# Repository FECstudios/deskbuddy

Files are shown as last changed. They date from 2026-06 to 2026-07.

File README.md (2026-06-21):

# DESK-BUDDY

A desk tool to control audio settings and access some cool macros easily!

We built this device because checking your media controls while you are working on something or while gaming is anoying. It's a compact, 3D-printed desktop companion featuring a 1.8" LCD screen, a rotary encoder, and two touch sensors. 

Instead of cluttering your computer screen, this device mirrors your actions instantly. Rotate the encoder to set the  volume or mute sounds, 

## Gallery
<p align="center">
  
</p>
<p align="center">
circuit_image (1)
</p>
<p align="center"><b>Perf board placement:</b></p>

<p align="center">
  
</p>

<p align="center">
  
</p>

<p align="center">
  
</p>

## What does it do
* **Rotate the encoder** -> Adjust system volume. The 1.8" LCD instantly shows a visual volume slider updating in real-time.
* **Click the encoder** -> Mute audio. The screen status switches to a muted speaker graphic.
* **Touch Sensor 1 (Macro)** -> Triggers a custom PC macro (such as a screenshot or opening youtube) with a visual confirmation popup on the LCD.
* **Touch Sensor 2 (Microphone)** -> Hardware mute toggle for your mic. The screen instantly displays a crossed-out microphone icon so you always know your exact status.

## Hardware
| Component | What it's for |
| :--- | :--- |
| **ESP32 Dev Board (38-pin)** | The microcontroller. Handles inputs, updates the screen state, and talks to the PC. |
| **1.8" ST7735 LCD Screen** | UI Display. Shows active status icons (mic status, volume bar, mute states). |
| **Rotary Encoder (KY-040)** | Digital volume knob + push button for master mute. |
| **TTP223 Touch Sensors (x2)** | Capacitive touch buttons for microphone mute and custom macro shortcuts. |
| **3D-Printed PLA Case** | Custom designed enclosure to fit perfectly into a desktop setup. |

## How it works
The ESP32 connects to your PC via USB and communicates with a lightweight companion script running on your computer to stay perfectly in sync.

1. **Input & Feedback:** When you interact with the hardware (rotating the knob or tapping a touch sensor), the ESP32 sends the command to the PC and instantly updates its own screen to reflect that action.
2. **Status Mirroring:** If you mute your microphone via the touch sensor, the PC script confirms the action, and the 1.8" LCD switches the UI to show a clear crossed-out microphone indicator. No more guessing if you are muted during Discord calls or online sessions.
3. **UI Rendering:** The screen acts as a dedicated hardware dashboard, drawing clean icons and progress bars based on the current state of your system audio and inputs.

## Building
1. **Printing**: Print the top.stl part with 0.20 layer height and add a pause on layer 14, then when the print pauses add your touch sensors with wires and pins removed and continue printing untill part is finished.
Then you can print rest of the parts (knob and bottom) normally with layer height of your choice
2. **Soldering**: Solder all of the components according to the schematics given above in *Gallery* and make sure to not burn the plastic while soldering the touch sensors. Solder the esp32 on the bottom of the perf board and solder the TFT screen on top of the esp32 as shown in the pictures above
3. **Assembly**: Slide in the perf board to the bottom part make sure the esp32 and the type c port hole allign and then slide in the rotary encoder on the left side of the bottom part. After all of the components are added simply click in the top and bottom parts together.

*The model was made with 0.4 tolerances in mind*

## Setup

### Prerequisites
* Arduino IDE 
* ESP32 Board Package (configured for 38-pin ESP32 Dev Module)
* Python 3.x (for the PC side volume/mic control script)
* Libraries: `Adafruit_GFX`, `Adafruit_ST7735`, `SPI`, `FreeSansBold18pt7b`, `FreeSans9pt7b` 

1. Upload `codes/deskbuddy.ino` to your ESP32 using the Arduino IDE (use a USB cable that supports data transfer).
2. Verify that all hardware components are working correctly.
3. Download `codes/sender.py` and install the required dependencies:

```bash
python -m pip install pyserial pycaw comtypes
```

4. Run:

```bash
python sender.py
```

Wait for the ESP32 to be detected, and you're ready to go.

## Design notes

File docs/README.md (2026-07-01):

# DESK-BUDDY

A desk tool to control audio settings and access some cool macros easily!

We built this device because checking your media controls while you are working on something or while gaming is anoying. It's a compact, 3D-printed desktop companion featuring a 1.8" LCD screen, a rotary encoder, and two touch sensors. 

Instead of cluttering your computer screen, this device mirrors your actions instantly. Rotate the encoder to set the  volume or mute sounds, 

## Project Overview

<p align="center">
  
</p>

## Gallery

### Finished Device

<p align="center">
  
</p>

### Internal Assembly

<p align="center">
  
  
</p>

<p align="center">
  
</p>

### Wiring Diagram

<p align="center">
  
</p>
<p align="center">
  
  (It is not the best or might have some errors on the kicad version im beginner on kicad)
</p>

<p align="center"><i>Complete wiring schematic.</i></p>

## What does it do
* **Rotate the encoder** -> Adjust system volume. The 1.8" LCD instantly shows a visual volume slider updating in real-time.
* **Click the encoder** -> Mute audio. The screen status switches to a muted speaker graphic.
* **Touch Sensor 1 (Macro)** -> Triggers a custom PC macro (such as a screenshot or opening youtube) with a visual confirmation popup on the LCD.
* **Touch Sensor 2 (Microphone)** -> Hardware mute toggle for your mic. The screen instantly displays a crossed-out microphone icon so you always know your exact status.

## Hardware
| Component | What it's for |
| :--- | :--- |
| **ESP32 Dev Board (38-pin)** | The microcontroller. Handles inputs, updates the screen state, and talks to the PC. |
| **1.8" ST7735 LCD Screen** | UI Display. Shows active status icons (mic status, volume bar, mute states). |
| **Rotary Encoder (KY-040)** | Digital volume knob + push button for master mute. |
| **TTP223 Touch Sensors (x2)** | Capacitive touch buttons for microphone mute and custom macro shortcuts. |
| **3D-Printed PLA Case** | Custom designed enclosure to fit perfectly into a desktop setup. |

## Bill of Materials (BoM)

| Part | Qty | Approx. Cost (TL) | Purchase Link |
|---|----:|---:|---|
| ESP-WROOM-32D Development Board (38-pin, USB-C) | 1 | 386.40 | https://www.robo90.com/esp-wroom-32-wifi-ve-bluetooth-gelistirme-karti-38-pin-esp32 |
| 1.8" 128×160 TFT LCD (ST7735) | 1 | 488.11 | https://www.robotistan.com/18-inc-lcd-display-module |
| KY-040 Rotary Encoder Module | 1 | 39.91 | https://www.komponentci.net/ky-040-rotary-encoder-modulu-pmu4057 |
| TTP223B Touch Sensor | 2 | 33.12 | https://www.robo90.com/tpp223b-dokunmatik-touch-sensor-modulu |
| **Total Estimated Cost** | | **₺947.54** | |

> Prices are approximate and may change over time.

## How it works
The ESP32 connects to your PC via USB and communicates with a lightweight companion script running on your computer to stay perfectly in sync.

1. **Input & Feedback:** When you interact with the hardware (rotating the knob or tapping a touch sensor), the ESP32 sends the command to the PC and instantly updates its own screen to reflect that action.
2. **Status Mirroring:** If you mute your microphone via the touch sensor, the PC script confirms the action, and the 1.8" LCD switches the UI to show a clear crossed-out microphone indicator. No more guessing if you are muted during Discord calls or online sessions.
3. **UI Rendering:** The screen acts as a dedicated hardware dashboard, drawing clean icons and progress bars based on the current state of your system audio and inputs.

## Steps to Reproduce
1. **Printing**: Print the top.stl part with 0.20 layer height and add a pause on layer 14, then when the print pauses add your touch sensors with wires and pins removed and continue printing untill part is finished.
Then you can print rest of the parts (knob and bottom) normally with layer height of your choice
2. **Soldering**: Solder all of the components according to the schematics given above in *Gallery* and make sure to not burn the plastic while soldering the touch sensors. Solder the esp32 on the bottom of the perf board and solder the TFT screen on top of the esp32 as shown in the pictures above
3. **Assembly**: Slide in the perf board to the bottom part make sure the esp32 and the type c port hole allign and then slide in the rotary encoder on the left side of the bottom part. After all of the components are added simply click in the top and bottom parts together.

The model was made with 0.4 tolerances in mind

## Setup

### Prerequisites
* Arduino IDE 
* ESP32 Board Package (configured for 38-pin ESP32 Dev Module)
* Python 3.x (for the PC side volume/mic control script)
* Libraries: `Adafruit_GFX`, `Adafruit_ST7735`, `SPI`, `FreeSansBold18pt7b`, `FreeSans9pt7b` 

1. Upload `codes/deskbuddy.ino` to your ESP32 using the Arduino IDE (use a USB cable that supports data transfer).
2. Verify that all hardware components are working correctly.
3. Download `codes/sender.py` and install the required dependencies:

```bash
python -m pip install pyserial pycaw comtypes
```

4. Run:

```bash
python sender.py
```

Wait for the ESP32 to be detected, and you're ready to go.

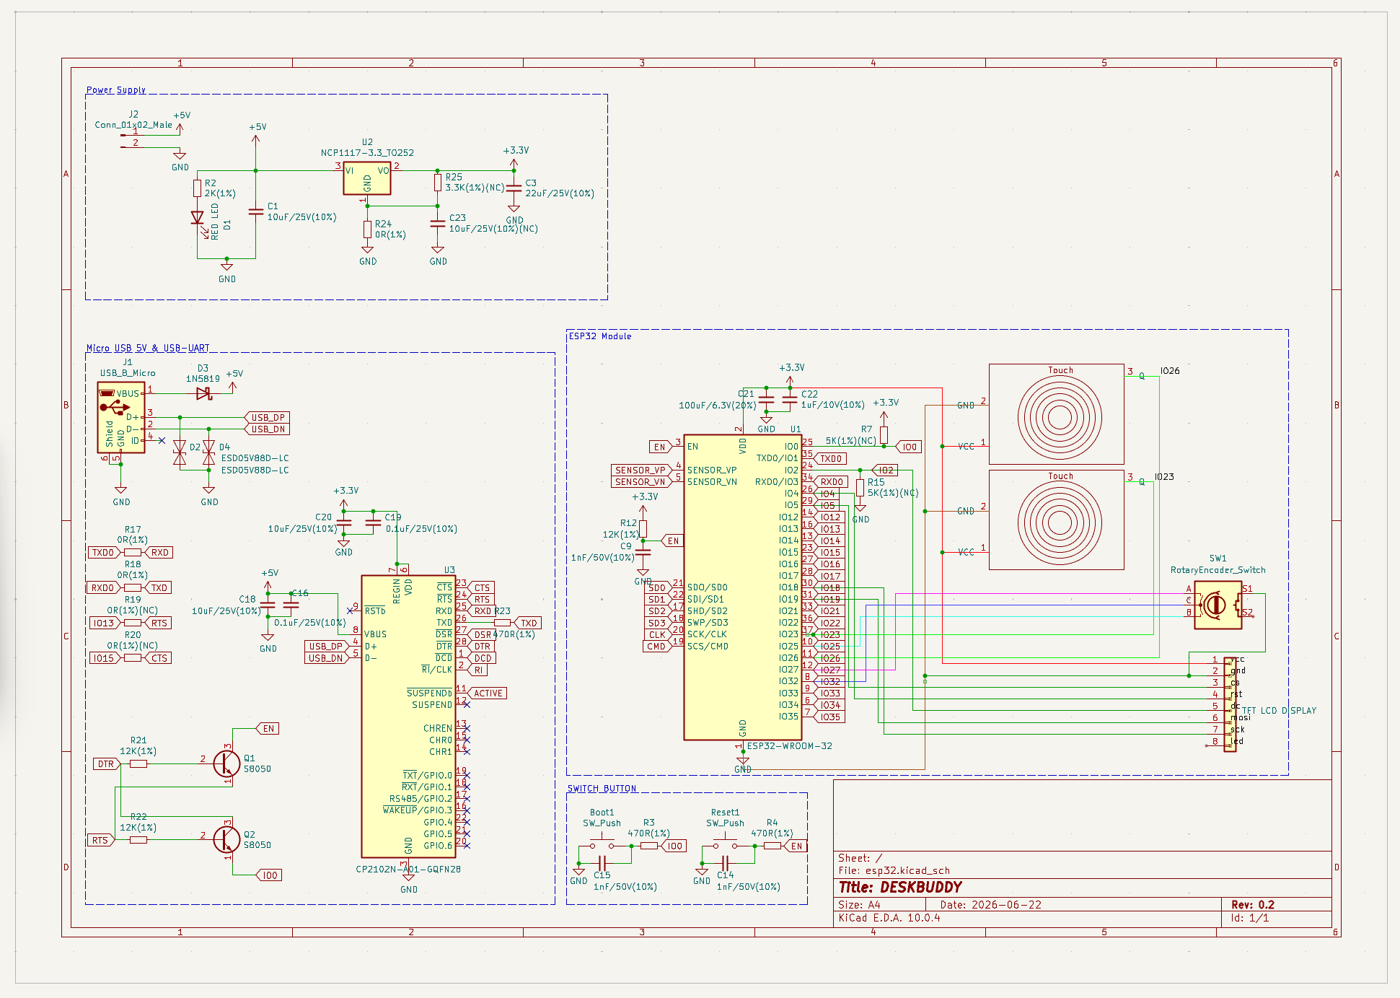
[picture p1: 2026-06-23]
schematics/image.png

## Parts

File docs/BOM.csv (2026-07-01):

Part Name | Quantity | Price | Link
Touch Sensor TTP223B | 2 | 16,56TL | https://www.robo90.com/tpp223b-dokunmatik-touch-sensor-modulu
128x160, General 1.8 inch LCD display Module | 1 | 488.11 TL | https://www.robotistan.com/18-inc-lcd-display-module
KY-040 Rotary Encoder Module | 1 | 39,91TL | https://www.komponentci.net/ky-040-rotary-encoder-modulu-pmu4057
Esp-Wroom-32D (type-c) | 1 | 386,40TL | https://www.robo90.com/esp-wroom-32-wifi-ve-bluetooth-gelistirme-karti-38-pin-esp32
Total Price |  | **₺947.54**

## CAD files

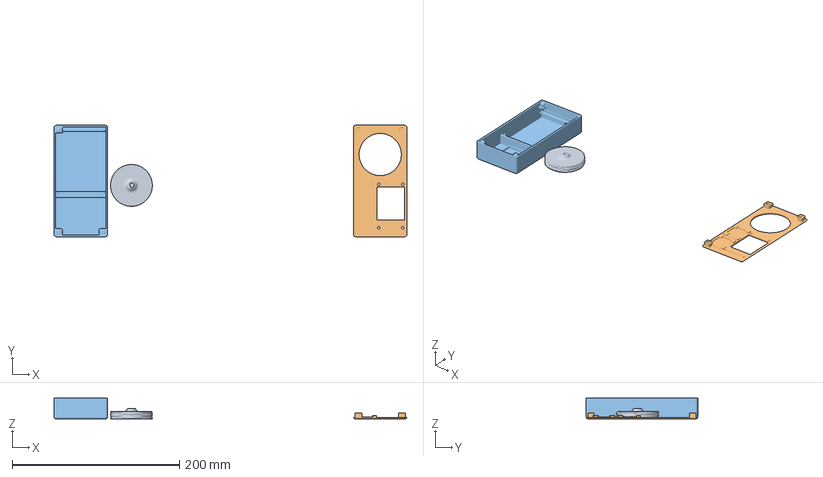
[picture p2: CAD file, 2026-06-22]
3dprint/deskbuddy.3mf
422.0 x 133.3 x 25.0 mm
knob.stl
top.stl
bottom.stl

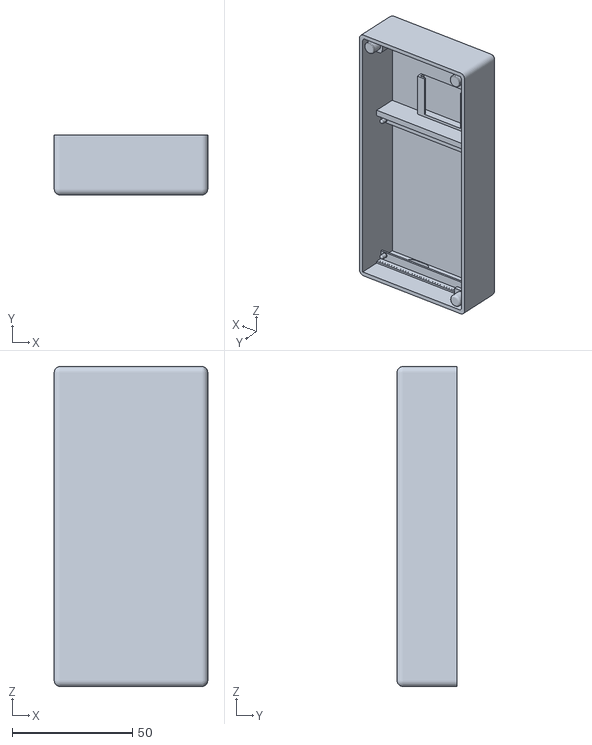
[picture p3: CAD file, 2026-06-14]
3dprint/bottom.stl
64.0 x 25.0 x 133.3

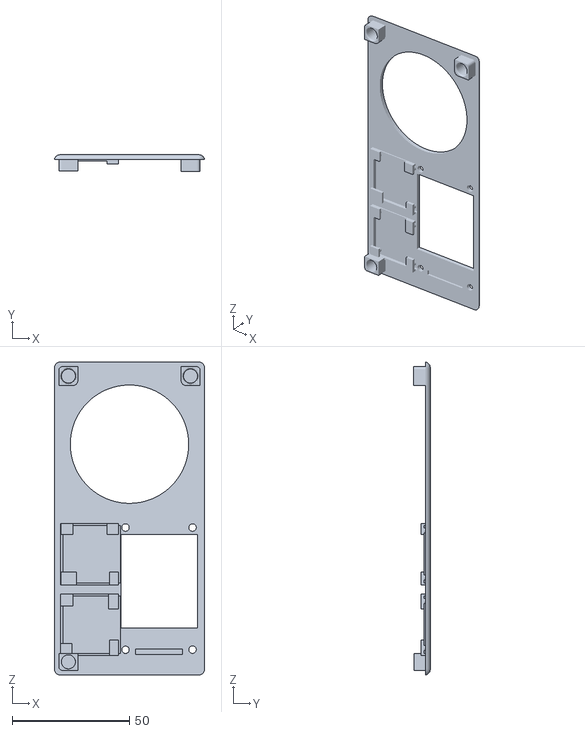
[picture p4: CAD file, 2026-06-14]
3dprint/top.stl
64.0 x 7.10 x 133.3

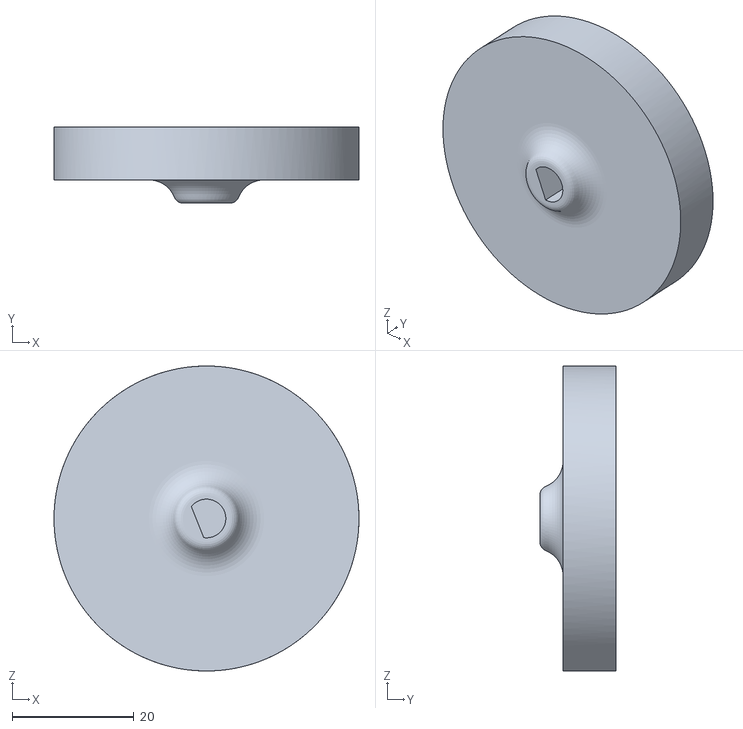
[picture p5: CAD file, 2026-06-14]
3dprint/knob.stl
50.0 x 12.5 x 50.0

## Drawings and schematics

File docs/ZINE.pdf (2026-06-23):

# D E S K B U D D Y

# your favorIte utIlIty tool

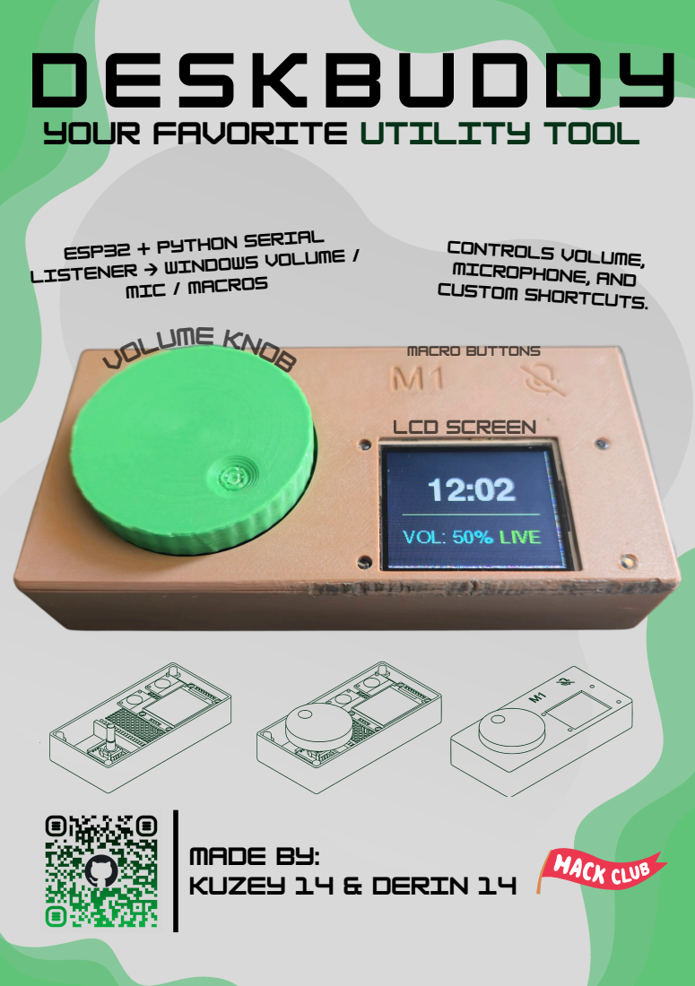
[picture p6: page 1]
Volume Knob; LCD SCreen; MACRO BUTTONS; Made by: Kuzey 14 & DerIn 14; Controls volume, mIcrophone, and custom shortcuts.; ESP32 + Python serIal; mIc / macros

lIstener → WIndows volume /

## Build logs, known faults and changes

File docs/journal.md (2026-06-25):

# DeskBuddy

- Exported at: 2026-06-21T15:25:05Z
- Project ID: 4344
- Entries: 17
- Exported from fallout and recorded via lookout

Message to the Horizons team:

If you could count the hours filmed via lookout it would mean a lot we tried to transfer this project from Fallout to Horizons due to visa reasons (the project has not been submitted to Fallout)

## Entry 1
- ID: 12566
- Author: D_R1N
- Created At: 2026-06-08T18:42:00Z
- 1h 4m tracked

### Content

Today I worked on the Desk Buddy project by learning and using KiCad to create and improve the circuit design. I also designed a poster to showcase the project, focusing on explaining its purpose, functionality, and key features in a clear and visually appealing format.

### Recording Links

- https://lookout.hackclub.com/api/media/732c8ba0-a21a-4e1c-85cd-4a641441a240/video.mp4
  


## Entry 2
- ID: 13017
- Author: 
- Created At: 2026-06-10T15:07:04Z
- 3h 50m tracked

### Content
Today I soldered the ESP and display onto the perfboard, completed the main hardware assembly, and ran a series of tests to make sure everything was working correctly. After fixing a few small issues, the setup was running as expected and ready for the next stage of development.

### Recording Links

- https://lookout.hackclub.com/api/media/19390815-d58f-4c3a-a059-772953b4d734/video.mp4



## Entry 3
- ID: 13019
- Author: craftfec
- Created At: 2026-06-10T15:11:53Z
- 1h 13m tracked

### Content

Today i worked on the knob design more than i should have and printed it but it still doesn't look very well

### Recording Links

- https://lookout.hackclub.com/api/media/c3755179-fb84-44b6-8a31-3a1aa7dcd7ff/video.mp4
  


## Entry 4
- ID: 13289
- Author: craftfec
- Created At: 2026-06-11T19:11:07Z
- 3h 4m tracked

### Content

This was the designing process of the DeskBuddy sadly i uploaded the video a few days after filming so hope you enjoy it 
Also i learned about connecting 3d printed parts while making this design

### Recording Links

- https://lookout.hackclub.com/api/media/a92febf3-f74a-4c93-ac2f-3d8974450e7d/video.mp4

## Entry 5
- ID: 13423
- Author: 
- Created At: 2026-06-12T09:11:34Z
- 3h 17m tracked

### Content

Spent some time working on DeskBuddy today. I soldered the rotary encoder and LCD display onto the perfboard, then wrote and ran test code to make sure everything was working properly. The tests went well and it's exciting to see the project slowly coming together.

### Recording Links

- https://lookout.hackclub.com/api/media/f283b0ac-b732-48af-818a-40508e89c2a5/video.mp4



## Entry 6
- ID: 13424
- Author: 
- Created At: 2026-06-12T09:16:55Z
- 44min tracked

### Content

Continued working on the DeskBuddy electronics today, focusing on soldering and assembly. While I worked on the hardware, my friend spent time refining the design and printing updated parts. Working on different areas simultaneously helped us move the project forward much faster.

### Recording Links

- https://www.youtube.com/watch?v=BgmVbupuWS4
  


## Entry 7
- ID: 13962
- Author: 
- Created At: 2026-06-14T12:47:21Z
- 1h 8m tracked

### Content

Spent some time working on DeskBuddy today. I soldered more of the components and kept building out the electronics. When I needed a break from soldering, I started designing the poster for the project and played around with a few different ideas for the layout.

### Recording Links

- https://lookout.hackclub.com/api/media/d2c67cb4-1a42-4405-bd3e-0cb8356158ea/video.mp4


## Entry 8
- ID: 14080
- Author: craftfec
- Created At: 2026-06-14T19:46:14Z
- 1h 30m tracked

### Content

Today i got most of the files ready for shipping. Created the GitHub repo and filled it with help from Derin, also wrote some test codes i successfully wrote the receiver code which will be a python script run from the pc and uploaded the CAD and 3d print files.

### Recording Links

- https://lookout.hackclub.com/api/media/ca90fd3a-f077-4b0d-8939-126cdd796fb7/video.mp4
  


## Entry 9
- ID: 14316
- Author: 
- Created At: 2026-06-15T20:44:35Z
- 6h 10m tracked

### Content

Today, I worked on my DeskBuddy project. I completed the soldering work, tested the code to ensure everything runs smoothly, and 3D printed its custom case. It was a productive day of combining hardware, software, and design.

### Recording Links

- https://lookout.hackclub.com/api/media/cef48a1d-7b74-49a0-b643-4330191fc3d0/video.mp4



## Entry 10
- ID: 14508
- Author: 
- Created At: 2026-06-16T12:30:20Z
- 1h tracked

### Content

Today, I focused on the DeskBuddy project. I finalized the Bill of Materials (BOM), completed the sensor testing and successfully updated the GitHub README. It was a productive day of documenting the hardware framework and ensuring all system diagnostics run smoothly.

### Recording Links

- https://lookout.hackclub.com/api/media/01b8f960-ebd3-4d82-9f8d-2516ebf4a3a7/video.mp4
- https://lookout.hackclub.com/api/media/e4955757-c1b6-4c76-b939-bbf9b6c7b74f/video.mp4



## Entry 11
- ID: 14593
- Author: 
- Created At: 2026-06-16T18:19:18Z
- 1h tracked

### Content

Today I spent some time improving DeskBuddy. I worked on the codebase, fixing issues and adding new functionality to make everything run more smoothly. I also continued refining the 3D design, making adjustments to improve both the appearance and the overall usability of the device. It's starting to feel much more polished, and I'm excited to keep pushing the project forward

### Recording Links

- https://lookout.hackclub.com/api/media/e6145abb-b70c-4924-bf2d-8ee2b85bff13/video.mp4


## Entry 12
- ID: 14983
- Author: craftfec
- Created At: 2026-06-18T12:40:14Z
- 4h 30m tracked

### Content

Today i worked on deskbuddy writing the python and the esp side code and got it working i then added the images to the zine design

### Recording Links

- https://lookout.hackclub.com/api/media/61a2feca-e964-420d-92f1-f0d4123bb827/video.mp4
- https://lookout.hackclub.com/api/media/8fe47c0b-c181-42f6-a2dc-169a25c2b767/video.mp4



## Entry 13
- ID: 14983
- Author: craftfec
- Created At: 2026-06-21 9:30pm
- Time Tracked: 1:11:46

### Content

Today i tried to transfer the project from fallout to horizons, created both of the projects for me and my teammate and mailed the horizons team about this but still no response...

### Recording Links
- https://lapse.hackclub.com/timelapse/802CU1dYqW50
- https://lapse.hackclub.com/timelapse/G2JajRXwvE7z
- https://lapse.hackclub.com/timelapse/nWsz_2K3OGzF

## Entry 14
- ID: 14983
- Author: craftfec
- Created At: 2026-06-22 9:14pm
- Time Tracked: 2:30:41
  
### Content

Today i started to finalize the shipping process, made schematics on both circitdesigner and kicad, created print profiles for the projects and uploaded them to makerworld https://makerworld.com/tr/models/2961161-deskbuddy-smart-media-controller#profileId-3319336



### Recording Links
- https://lapse.hackclub.com/timelapse/zzBnF3nzvdZW
- https://lapse.hackclub.com/timelapse/s5m_3yv74e1e
- https://lapse.hackclub.com/timelapse/giknjamv4afs
- https://lapse.hackclub.com/timelapse/sHuYStKZbtmM

## Entry 15
- ID: 14983
- Author: 
- Created At: 2026-06-22 9:18pm
- Time Tracked: 58:12
  
### Content

Today i tried to paint the project with some metalic gray colors and now i am waiting for the paint to dry and also i worked on the code but sadly the recordings got lost and also i wrote journals



### Recording Links
- https://lapse.hackclub.com/timelapse/VPNcZLikPkJ_
- https://lapse.hackclub.com/timelapse/D4sbDbbKvaBL

## Entry 16
- ID: 14983
- Author: 
- Created At: 2026-06-25 10:25am
- Time Tracked: 1:46:05
  
### Content

Today i continued by getting the project shipping ready. Journaled for the project, made schematic designs on kicad and worked on the poster 



### Recording Links
- https://lapse.hackclub.com/timelapse/ujkxyN6umV80
- https://lapse.hackclub.com/timelapse/iAX3YhSjHB24
- https://lapse.hackclub.com/timelapse/kg9KbqnS6cpq
- https://lapse.hackclub.com/timelapse/9ATnQ195jXJ8

## Entry 17
- ID: 14983
- Author: D_R1N
- Created At: 2026-06-25 10:45am
- Time Tracked: 37:01
  
### Content

Finally the project and the github page is finished now all we need to do is send to review!



### Recording Links
- https://lapse.hackclub.com/timelapse/_qu0E8XzCpRS

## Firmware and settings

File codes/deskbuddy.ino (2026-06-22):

#include <Adafruit_GFX.h>
#include <Adafruit_ST7735.h>
#include <SPI.h>
#include <Fonts/FreeSansBold18pt7b.h>
#include <Fonts/FreeSans9pt7b.h>

// ─── Screen Pin Definitions ───────────────────────────────────────────────────────
#define TFT_CS     5
#define TFT_DC     2
#define TFT_RST    4
#define TFT_MOSI   19
#define TFT_SCLK   18

const int TOUCH_PIN1 = 26;
const int TOUCH_PIN2 = 23;
const int TOUCH_PIN  = TOUCH_PIN1;
const int CLK_PIN   = 25;
const int DT_PIN    = 32;
const int SW_PIN    = 27;

// ─── Display Setup ─────────────────────────────────────────────────────────
Adafruit_ST7735 tft = Adafruit_ST7735(TFT_CS, TFT_DC, TFT_RST);
GFXcanvas16 canvas(160, 128);

// ─── State Variables ───────────────────────────────────────────────────────
int   volume        = 50;
bool isMicMuted     = false;
bool isIncreasing   = true; 

// Idle & Time System
unsigned long lastActivityTime = 0;
const unsigned long IDLE_TIMEOUT = 10000; 
int hr = 12, mn = 0, sc = 0;              
unsigned long lastClockTick = 0;

// Encoder
volatile int encoderDelta = 0;
int lastClkState;

// Button debounce / double-click
bool          lastButtonState  = HIGH;
unsigned long firstClickTime   = 0;
bool          waitingForDouble = false;
const unsigned long DOUBLE_CLICK_MS = 500;

// Touch
bool lastTouchState  = false;
bool lastTouch2State = false;

// ─── Forward Declarations ──────────────────────────────────────────────────
void drawScreen();
void pushCanvas();
void playM1Animation();
void playMuteAnimation();
void sendVolume();
void sendMicState();
void handleSerialInput();
void IRAM_ATTR encoderISR();

// ─── Drawing ───────────────────────────────────────────────────────────────

void drawScreen() {
  canvas.fillScreen(ST7735_BLACK);

  // 1) IDLE SCREEN
  if (millis() - lastActivityTime > IDLE_TIMEOUT) {
    canvas.setFont(&FreeSansBold18pt7b);
    canvas.setTextColor(ST7735_WHITE);
    
    char timeStr[9];
    snprintf(timeStr, sizeof(timeStr), "%02d:%02d", hr, mn);
    
    int16_t x1, y1;
    uint16_t tw, th;
    canvas.getTextBounds(timeStr, 0, 0, &x1, &y1, &tw, &th);
    canvas.setCursor((160 - tw) / 2, 58);
    canvas.print(timeStr);
    
    canvas.drawFastHLine(15, 74, 130, 0x4444);
    
    canvas.setFont(&FreeSans9pt7b);
    
    char volStr[12];
    snprintf(volStr, sizeof(volStr), "VOL: %d%%", volume);
    canvas.setTextColor(ST7735_CYAN);
    canvas.setCursor(15, 104);
    canvas.print(volStr);
    
    if (isMicMuted) {
      canvas.setTextColor(ST7735_RED);
      canvas.setCursor(95, 104);
      canvas.print("MUTED");
    } else {
      canvas.setTextColor(ST7735_GREEN);
      canvas.setCursor(105, 104);
      canvas.print("LIVE");
    }
    return;
  }

  // 2) MIC MUTED SCREEN
  if (isMicMuted) {
    int16_t x1, y1;
    uint16_t tw, th;

    canvas.setFont(&FreeSansBold18pt7b);
    canvas.setTextColor(ST7735_RED);
    canvas.getTextBounds("MIC OFF", 0, 0, &x1, &y1, &tw, &th);
    canvas.setCursor((160 - tw) / 2, 58);
    canvas.print("MIC OFF");

    canvas.setFont(&FreeSans9pt7b);
    canvas.setTextColor(0x7800);
    canvas.getTextBounds("(muted)", 0, 0, &x1, &y1, &tw, &th);
    canvas.setCursor((160 - tw) / 2, 88);
    canvas.print("(muted)");
  }
  // 3) VOLUME CONTROL SCREEN
  else {
    canvas.setFont(&FreeSans9pt7b);
    canvas.setTextColor(isIncreasing ? ST7735_GREEN : ST7735_RED);
    canvas.setCursor(135, 22);
    canvas.print(isIncreasing ? "+" : "-");

    canvas.setFont(&FreeSansBold18pt7b);
    canvas.setTextColor(ST7735_WHITE);

    int16_t  x1, y1;
    uint16_t tw, th;
    char volStr[8];
    snprintf(volStr, sizeof(volStr), "%d", volume);
    canvas.getTextBounds(volStr, 0, 0, &x1, &y1, &tw, &th);

    int numX = (160 - (int)tw - 20) / 2;
    canvas.setCursor(numX, 68);
    canvas.print(volStr);

    canvas.setFont(&FreeSans9pt7b);
    canvas.setTextColor(0xC618);
    canvas.print("%");

    uint16_t barColor = isIncreasing ? ST7735_GREEN : ST7735_RED;
    canvas.drawRoundRect(14, 85, 132, 22, 6, ST7735_WHITE);
    int barW = map(volume, 0, 100, 0, 128);
    if (barW > 0) {
      canvas.fillRoundRect(16, 87, barW, 18, 4, barColor);
    }
  }
}

void pushCanvas() {
  tft.drawRGBBitmap(0, 0, canvas.getBuffer(), 160, 128);
}

void updateDisplay() {
  drawScreen();
  pushCanvas();
}

// ─── M1 Animation ──────────────────────────────────────────────────────────
void playM1Animation() {
  for (int i = 0; i < 3; i++) {
    canvas.fillScreen(ST7735_BLACK);
    pushCanvas();
    delay(25);
  }

  canvas.setFont(&FreeSansBold18pt7b);
  for (int r = 0; r <= 31; r += 3) {
    canvas.fillScreen(ST7735_BLACK);
    canvas.setTextColor(((uint16_t)r) << 11);
    canvas.setCursor(50, 75);
    canvas.print("M1");
    pushCanvas();
    delay(12);
  }

  delay(500);

  for (int r = 31; r >= 0; r -= 3) {
    canvas.fillScreen(ST7735_BLACK);
    canvas.setTextColor(((uint16_t)r) << 11);
    canvas.setCursor(50, 75);
    canvas.print("M1");
    pushCanvas();
    delay(12);
  }

  updateDisplay();
}

void playMuteAnimation() {
  for (int i = 0; i < 3; i++) {
    canvas.fillScreen(ST7735_BLACK);
    pushCanvas();
    delay(25);
  }

  canvas.setFont(&FreeSansBold18pt7b);
  for (int r = 0; r <= 31; r += 3) {
    canvas.fillScreen(ST7735_BLACK);
    canvas.setTextColor(((uint16_t)r) << 11);
    canvas.setCursor(50, 75);
    canvas.print("MUTED");
    pushCanvas();
    delay(12);
  }

  delay(500);

  for (int r = 31; r >= 0; r -= 3) {
    canvas.fillScreen(ST7735_BLACK);
    canvas.setTextColor(((uint16_t)r) << 11);
    canvas.setCursor(50, 75);
    canvas.print("MUTED");
    pushCanvas();
    delay(12);
  }

  updateDisplay();
}

// ─── Serial Communication & Parsing ────────────────────────────────────────
void sendVolume() {
  Serial.print("VOL:");
  Serial.println(volume);
}

void sendMicState() {
  Serial.println(isMicMuted ? "MIC:OFF" : "MIC:ON");
}

void handleSerialInput() {
  while (Serial.available() > 0) {
    String input = Serial.readStringUntil('\n');
    input.trim();
    
    // Expects "TIME:HH:MM:SS"
    if (input.startsWith("TIME:")) {
      int firstColon = input.indexOf(':');
      int secondColon = input.indexOf(':', firstColon + 1);
      int thirdColon = input.indexOf(':', secondColon + 1);
      
      if (firstColon != -1 && secondColon != -1) {
        String hrStr = input.substring(firstColon + 1, secondColon);
        String mnStr = (thirdColon != -1) ? input.substring(secondColon + 1, thirdColon) : input.substring(secondColon + 1);
        String scStr = (thirdColon != -1) ? input.substring(thirdColon + 1) : "0";
        
        hr = hrStr.toInt();
        mn = mnStr.toInt();
        sc = scStr.toInt();
        
        lastClockTick = millis();
        
        if (millis() - lastActivityTime > IDLE_TIMEOUT) {
          updateDisplay();
        }
      }
    }
    else if (input.startsWith("VOL:")) {
      String volStr = input.substring(4);
      int newVolume = volStr.toInt();
      newVolume = constrain(newVolume, 0, 100);
      if (newVolume != volume) {
        volume = newVolume;
        lastActivityTime = millis();
        updateDisplay();
      }
    }
  }
}

// ─── Encoder ISR ───────────────────────────────────────────────────────────
void IRAM_ATTR encoderISR() {
  int clkNow = digitalRead(CLK_PIN);
  if (clkNow != lastClkState && clkNow == LOW) {
    encoderDelta = (digitalRead(DT_PIN) != clkNow) ? 1 : -1;
  }
  lastClkState = clkNow;
}

// ─── Setup ─────────────────────────────────────────────────────────────────
void setup() {
  pinMode(TFT_CS,   OUTPUT);
  pinMode(TFT_DC,   OUTPUT);
  pinMode(TFT_RST,  OUTPUT);
  delay(500);

  Serial.begin(115200);

  pinMode(TOUCH_PIN, INPUT);
  pinMode(TOUCH_PIN2, INPUT);
  pinMode(CLK_PIN,   INPUT_PULLUP);
  pinMode(DT_PIN,    INPUT_PULLUP);
  pinMode(SW_PIN,    INPUT_PULLUP);

  lastClkState = digitalRead(CLK_PIN);
  attachInterrupt(digitalPinToInterrupt(CLK_PIN), encoderISR, CHANGE);

  SPI.begin(TFT_SCLK, -1, TFT_MOSI, TFT_CS);
  tft.initR(INITR_BLACKTAB);
  tft.setRotation(3); 

  canvas.fillScreen(ST7735_BLACK);
  lastActivityTime = millis();
  lastClockTick = millis();
  updateDisplay();

  Serial.println("DeskBuddy ready.");
}

// ─── Loop ──────────────────────────────────────────────────────────────────
void loop() {

  // Update clock in background
  if (millis() - lastClockTick >= 1000) {
    lastClockTick += 1000;
    sc++;
    if (sc >= 60) { sc = 0; mn++; }
    if (mn >= 60) { mn = 0; hr++; }
    if (hr >= 24) { hr = 0; }
    
    if (millis() - lastActivityTime > IDLE_TIMEOUT) {
      updateDisplay();
    }
  }

  handleSerialInput();

  // Handle Encoder
  if (encoderDelta != 0) {
    lastActivityTime = millis();
    int step = 2;

    if (isMicMuted) {
      isMicMuted  = false;
      isIncreasing = true;
      sendMicState();
    } else {
      if (isIncreasing) {
        volume = constrain(volume + (encoderDelta > 0 ? step : -step), 0, 100);
      } else {
        volume = constrain(volume + (encoderDelta > 0 ? -step : step), 0, 100);
      }
      sendVolume();
    }

    encoderDelta = 0;
    updateDisplay();
  }

  // Handle Button
  bool btnNow = digitalRead(SW_PIN);


    // Handle Touch
  bool touch2Now = (digitalRead(TOUCH_PIN2) == HIGH);

  if (touch2Now && !lastTouch2State) {
    lastActivityTime = millis();
    Serial.println("MUTE:RUN");
    isMicMuted = !isMicMuted;
    playMuteAnimation();
    sendMicState();
  }

  lastTouch2State = touch2Now;

  delay(5); 


  if (btnNow == LOW && lastButtonState == HIGH) {
    lastActivityTime = millis();
    unsigned long now = millis();

    volume = 0;
    sendVolume();

    updateDisplay();
  }

  if (waitingForDouble && (millis() - firstClickTime > DOUBLE_CLICK_MS)) {
    isIncreasing    = !isIncreasing;
    waitingForDouble = false;
    updateDisplay();
  }

  lastButtonState = btnNow;

  // Handle Touch
  bool touchNow = (digitalRead(TOUCH_PIN) == HIGH);

  if (touchNow && !lastTouchState) {
    lastActivityTime = millis();
    Serial.println("MACRO:RUN");
    playM1Animation();
  }

  lastTouchState = touchNow;

  delay(5); 
}

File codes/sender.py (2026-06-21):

import sys
import time
import logging
import webbrowser
from ctypes import cast, POINTER


import serial
import serial.tools.list_ports

from comtypes import CLSCTX_ALL, CoInitialize, CoUninitialize
from pycaw.pycaw import AudioUtilities, IAudioEndpointVolume
from pycaw.constants import CLSID_MMDeviceEnumerator
from comtypes.client import CreateObject
from pycaw.pycaw import IMMDeviceEnumerator, EDataFlow, ERole


logging.basicConfig(
    level=logging.INFO,
    format="[%(asctime)s] %(levelname)s  %(message)s",
    datefmt="%H:%M:%S",
)
log = logging.getLogger("DeskBuddy")

BAUD_RATE          = 115200
RECONNECT_DELAY_S  = 3          # seconds between reconnect attempts
READ_TIMEOUT_S     = 1          # serial read timeout
ESP32_USB_IDS      = [          # known ESP32 USB vendor IDs (decimal)
    0x10C4,  # Silicon Labs CP210x
    0x1A86,  # CH340 / CH341
    0x0403,  # FTDI
    0x303A,  # Espressif native USB (ESP32-S3 etc.)
]


# ─── Port Auto-Detection ────────────────────────────────────────────────────

def find_esp32_port() -> str | None:
    """Scan available COM ports and return the first that looks like an ESP32."""
    ports = serial.tools.list_ports.comports()
    for p in ports:
        vid = p.vid  # may be None for ports without USB info
        if vid is not None and vid in ESP32_USB_IDS:
            log.info("Auto-detected ESP32 on %s  (VID=0x%04X, %s)", p.device, vid, p.description)
            return p.device
        # Fallback: description heuristic
        desc = (p.description or "").lower()
        if any(k in desc for k in ("cp210", "ch340", "ch341", "ftdi", "esp", "uart")):
            log.info("Auto-detected likely ESP32 on %s  (%s)", p.device, p.description)
            return p.device

    log.warning("No ESP32 detected. Available ports: %s",
                [p.device for p in ports] or ["none"])
    return None


# ─── Windows Audio — Master Volume ─────────────────────────────────────────

def get_volume_controller() -> POINTER(IAudioEndpointVolume) | None:
    """Return a pycaw volume controller for the default audio playback endpoint."""
    try:
        devices = AudioUtilities.GetSpeakers()
        interface = devices.Activate(IAudioEndpointVolume._iid_, CLSCTX_ALL, None)
        ctrl = cast(interface, POINTER(IAudioEndpointVolume))
        log.info("Volume controller acquired.")
        return ctrl
    except Exception as exc:
        log.error("Could not acquire volume controller: %s", exc)
        return None


def set_system_volume(ctrl: POINTER(IAudioEndpointVolume), percent: int) -> None:
    """Set Windows master volume to *percent* (0–100)."""
    scalar = max(0.0, min(1.0, percent / 100.0))
    try:
        ctrl.SetMasterVolumeLevelScalar(scalar, None)
        log.info("Volume → %d%%", percent)
    except Exception as exc:
        log.error("set_system_volume failed: %s", exc)

def get_system_volume(ctrl: POINTER(IAudioEndpointVolume)) -> int | None:
    """Return the current Windows master volume as a percent."""
    try:
        scalar = ctrl.GetMasterVolumeLevelScalar()
        percent = round(max(0.0, min(1.0, scalar)) * 100)
        return percent
    except Exception as exc:
        log.error("Could not read system volume: %s", exc)
        return None


def send_current_volume(ser: serial.Serial, vol_ctrl: POINTER(IAudioEndpointVolume) | None) -> None:
    """Send the current system volume to the ESP32."""
    if vol_ctrl is None:
        log.warning("Volume controller unavailable; cannot sync current volume.")
        return

    if ser is None or not ser.is_open:
        return

    percent = get_system_volume(vol_ctrl)
    if percent is None:
        return

    try:
        ser.write(f"VOL:{percent}\n".encode("utf-8"))
        log.info("Current volume sent to ESP32: %d%%", percent)
    except Exception as exc:
        log.error("Failed to send current volume: %s", exc)

# ─── Windows Audio — Microphone Mute ───────────────────────────────────────

def get_mic_controller() -> POINTER(IAudioEndpointVolume) | None:
    """Return a pycaw volume/mute controller for the default capture endpoint."""
    try:
        enumerator = CreateObject(CLSID_MMDeviceEnumerator, interface=IMMDeviceEnumerator)
        mic_device = enumerator.GetDefaultAudioEndpoint(EDataFlow.eCapture.value, ERole.eConsole.value)
        interface   = mic_device.Activate(IAudioEndpointVolume._iid_, CLSCTX_ALL, None)
        ctrl        = cast(interface, POINTER(IAudioEndpointVolume))
        log.info("Microphone controller acquired.")
        return ctrl
    except Exception as exc:
        log.error("Could not acquire microphone controller: %s", exc)
        return None


def set_mic_mute(ctrl: POINTER(IAudioEndpointVolume), muted: bool) -> None:
    """Mute or unmute the default capture endpoint."""
    try:
        ctrl.SetMute(1 if muted else 0, None)
        log.info("Microphone → %s", "MUTED" if muted else "UNMUTED")
    except Exception as exc:
        log.error("set_mic_mute failed: %s", exc)


# ─── Macro ──────────────────────────────────────────────────────────────────

def run_macro() -> None:
    """Tarayıcıda YouTube'u açan makro."""
    log.info("MACRO triggered — Opening YouTube...")
    try:
        webbrowser.open("https://www.youtube.com")
    except Exception as exc:
        log.error("Failed to open YouTube: %s", exc)


# ─── PC to ESP32 Time Sync ──────────────────────────────────────────────────

def send_time_sync(ser: serial.Serial) -> None:
    """Sends the current local PC time to the ESP32."""
    if ser and ser.is_open:
        time_str = time.strftime("TIME:%H:%M:%S\n")
        try:
            ser.write(time_str.encode("utf-8"))
            log.info("Time sync sent to ESP32: %s", time_str.strip())
        except Exception as exc:
            log.error("Failed to send time sync: %s", exc)


# ─── Message Dispatch ───────────────────────────────────────────────────────
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

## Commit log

2026-06-14 3d print files
    [bottom.stl, knob.stl, top.stl]
2026-06-17 Add sender.py for ESP32 communication and audio control
2026-06-21 all of the stls into one
    [deskbuddy.3mf]
2026-06-23 schematics upload
    [deskbuddy.kicad_sch]
2026-07-01 Add Bill of Materials section to README
    Added a Bill of Materials (BoM) section with estimated costs and purchase links for components.
